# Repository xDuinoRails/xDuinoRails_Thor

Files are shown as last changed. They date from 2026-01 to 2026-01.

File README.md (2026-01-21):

# mtc21/plux16 Semi-Decoder for Seeed XIAO boards

Make a Seeed XIAO board a mtc21 decoder, all the electronics needed is on this little board:
- mtc21/plux16 compatible connector
- DC Motor
- 2x Functions
- DCC / DCC-ACK / RailCom

Open-Source [schematics](xDuinoRails-Thor-M-schematic.pdf) and [PCB design](xDuinoRails-Thor-M-PCB_All.pdf) included.

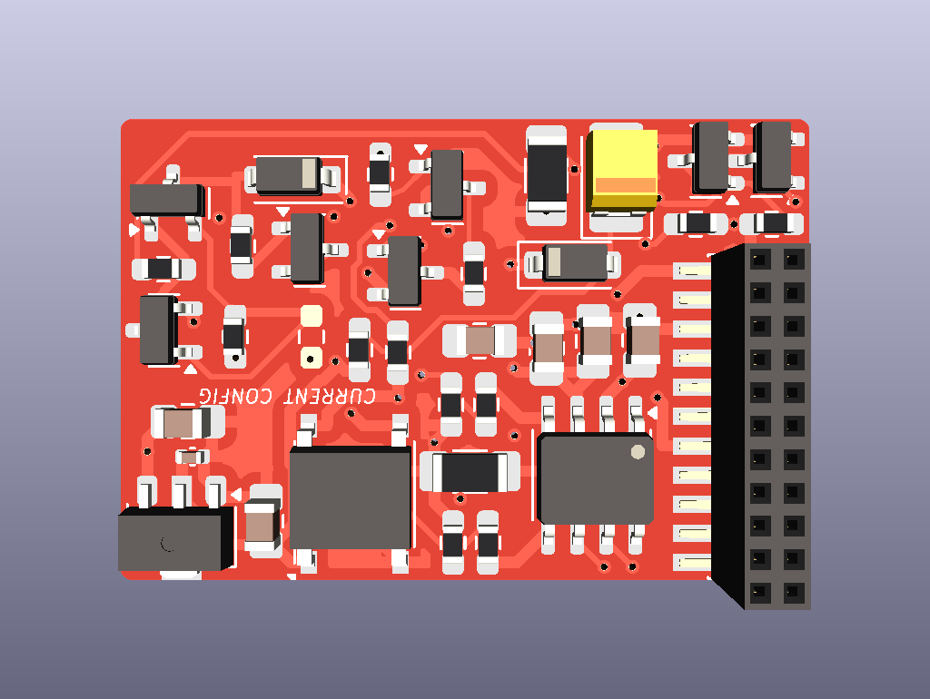
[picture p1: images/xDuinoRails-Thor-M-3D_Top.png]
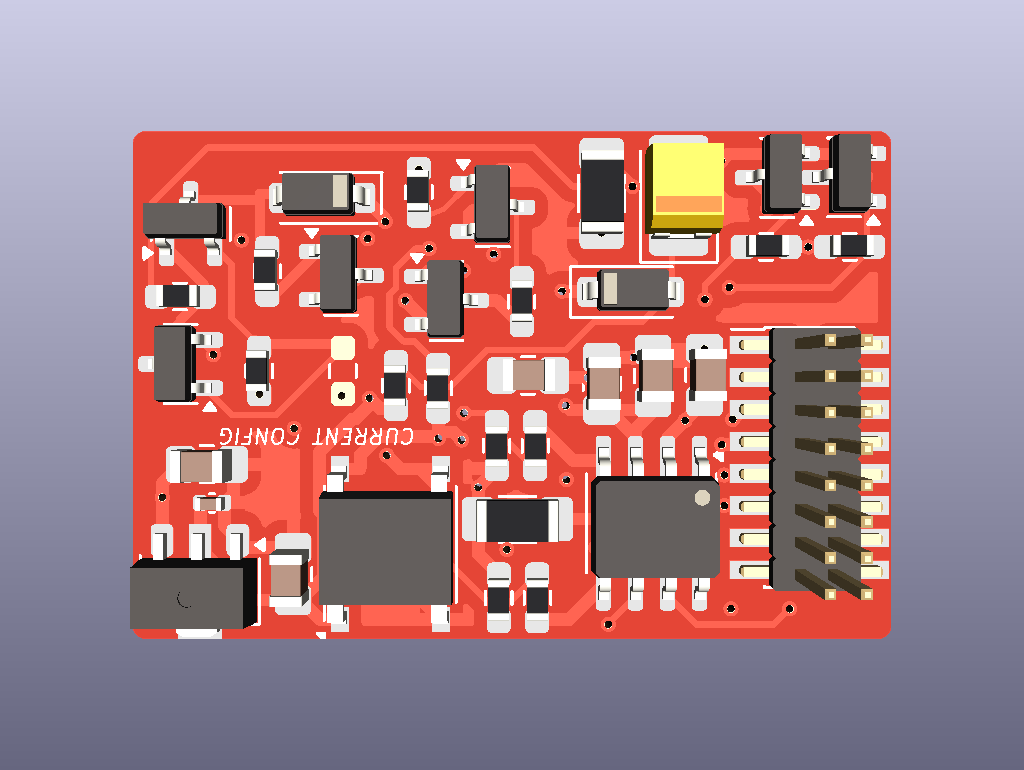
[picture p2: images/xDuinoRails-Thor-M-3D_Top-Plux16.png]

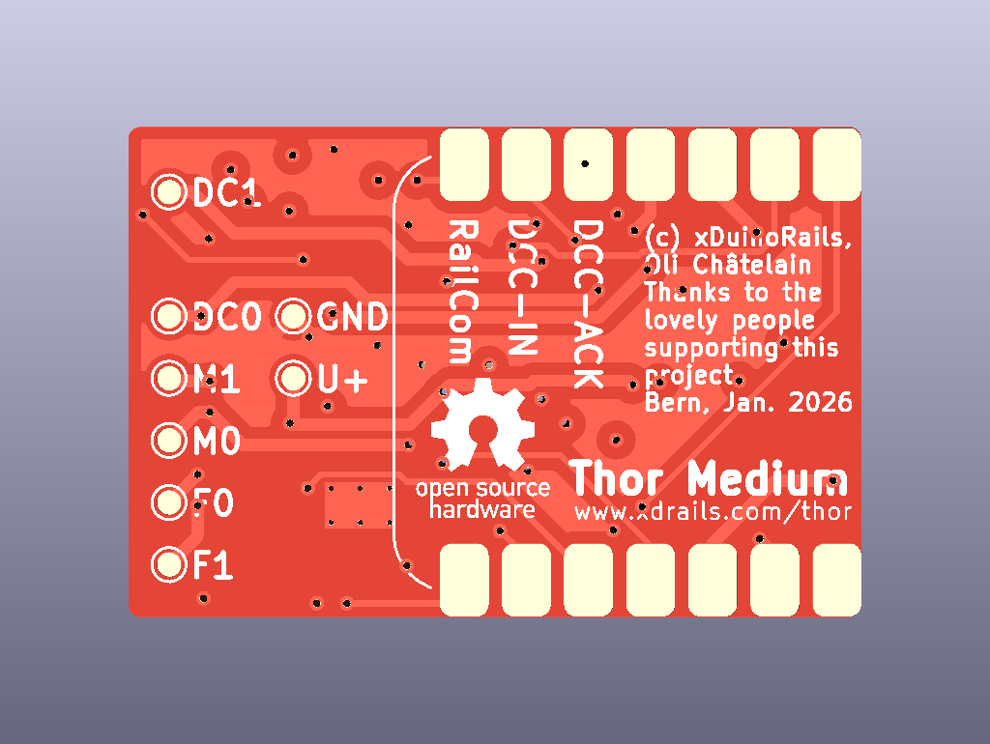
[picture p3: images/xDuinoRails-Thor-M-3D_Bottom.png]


## Wiring

```
                     +--------------------+      +--------------------+         +---------------+
                     |      RP2040        |      |     BDR-6133       |         |     Motor     |
                     |    (Top View)      |      |    Motor Driver    |         | DC brushed    |
                     +--------------------+      +--------------------+         +---------------+
                     |                5v  |      |                    |         |               |
          ---``|<----| D15 (LED)      GND |      |                    |         |               |
          ---``|<----| D16 (LED)      3v3 |      |                    |         |               |
                     |                    |      |                    |         |               |
                     |        (PWM B) D8  |----->| InB           OutB |=====+==>| B             |
                     |        (PWM A) D7  |----->| InA           OutA |==+==|==>| A             |
                     |                    |      +---------+----------+  |  |   +---------------+
                     |       (Shut)   A2  |<.............../             |  |
                     |       (bEMF B) A1  |<----------------------------/   |
                     |       (bEMF A) A0  |<-------------------------------/
                     |                    |
                     |                    |      +--------------------+
                     |                    |      | Functions          |
                     |                    |      +--------------------+
                     |         F0f    D9  |----->| F0f                |
                     |         F0b    D10 |----->| F0b                |
                     |                    |      +---------+----------+
                     |       (Shut)   A3  |<.............../

                     |                    |      +--------------------+
                     |                    |      | DCC / Railcom      |
                     |                    |      +--------------------+
                     |     DCC-ACK    D4  |----->| DCC-ACK            |
                     |     DCC/MM/SX  D5  |<-----| DCC/MM/SX          |
                     |     RailCom    D6  |----->| RailCom            |
                     |                    |      +---------+----------+
                     |       (Shut)   A3  |<.............../
                     +--------------------+
```

## Purchase your copy

If you want an easy way to try this board, order one on tindie:
- https://www.tindie.com/products/chatelao/diy-dccmm-decoder-for-xiao-boards

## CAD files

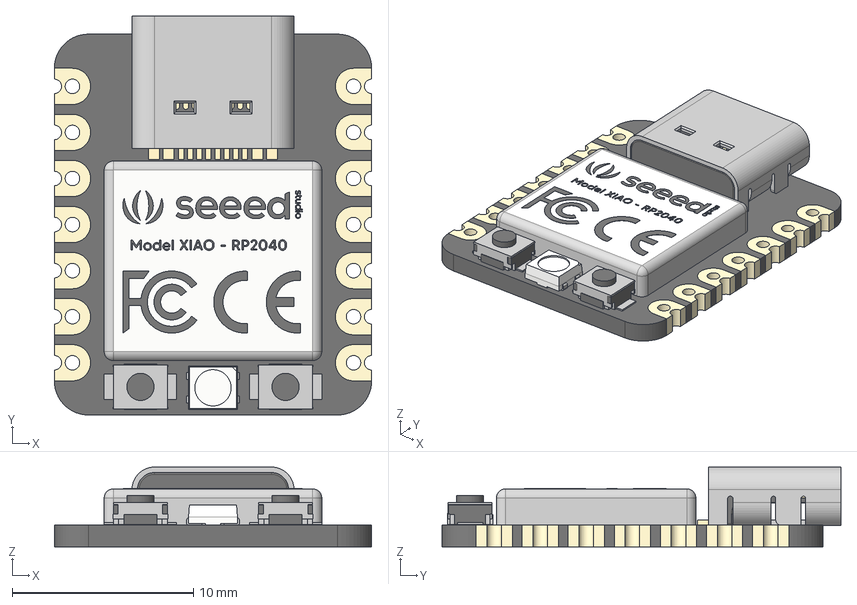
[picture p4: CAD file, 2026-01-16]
__lib/3d/SeeedStudio-XIAO_RP2040-v26.step
17.5 x 22.0 x 4.40 mm
type-c v2
smd_button v3
DOUT
DIN
VSS
VDD
smd_button v3(Mirror)

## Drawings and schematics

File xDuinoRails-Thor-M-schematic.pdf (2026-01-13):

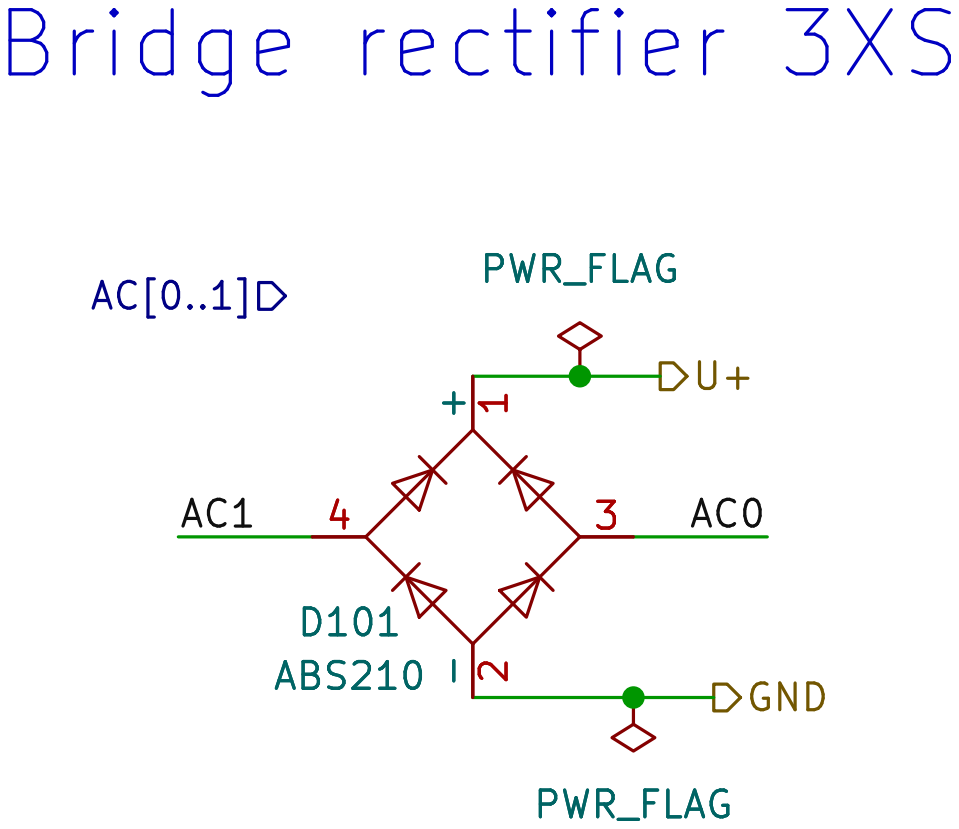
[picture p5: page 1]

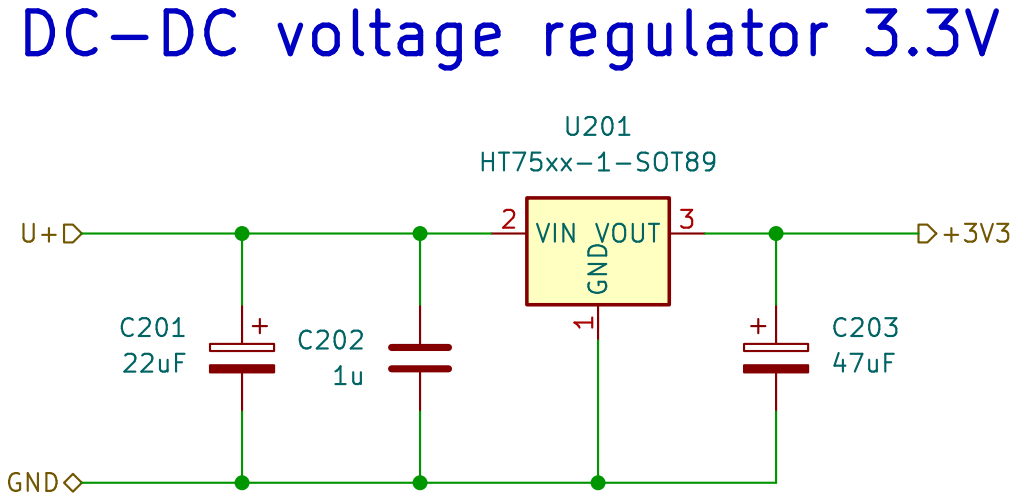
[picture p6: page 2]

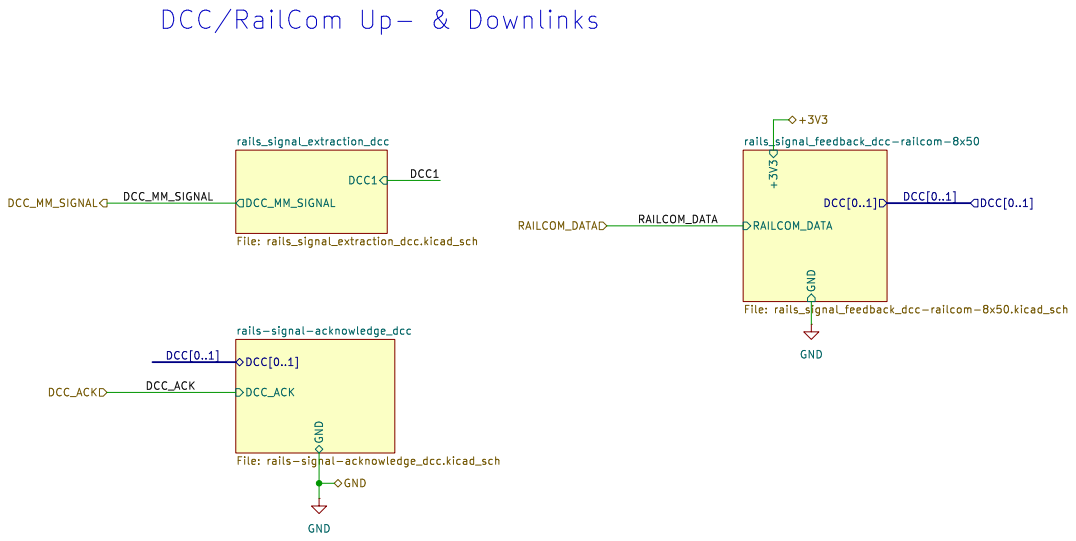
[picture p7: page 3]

rails-signal-acknowledge_dcc File: rails-signal-acknowledge_dcc.kicad_sch

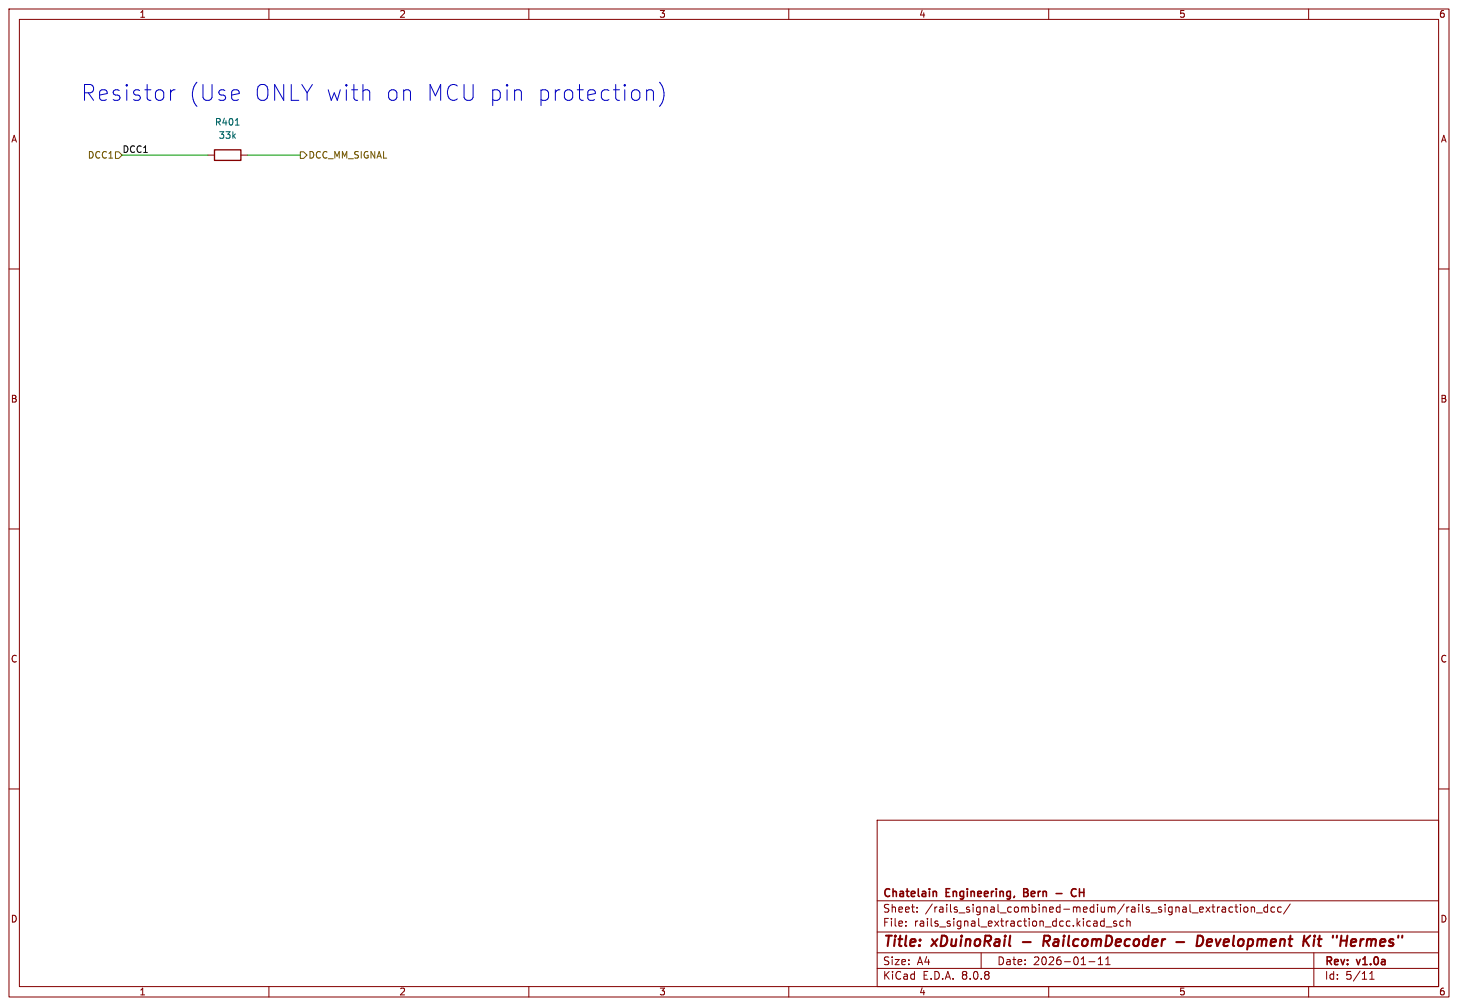
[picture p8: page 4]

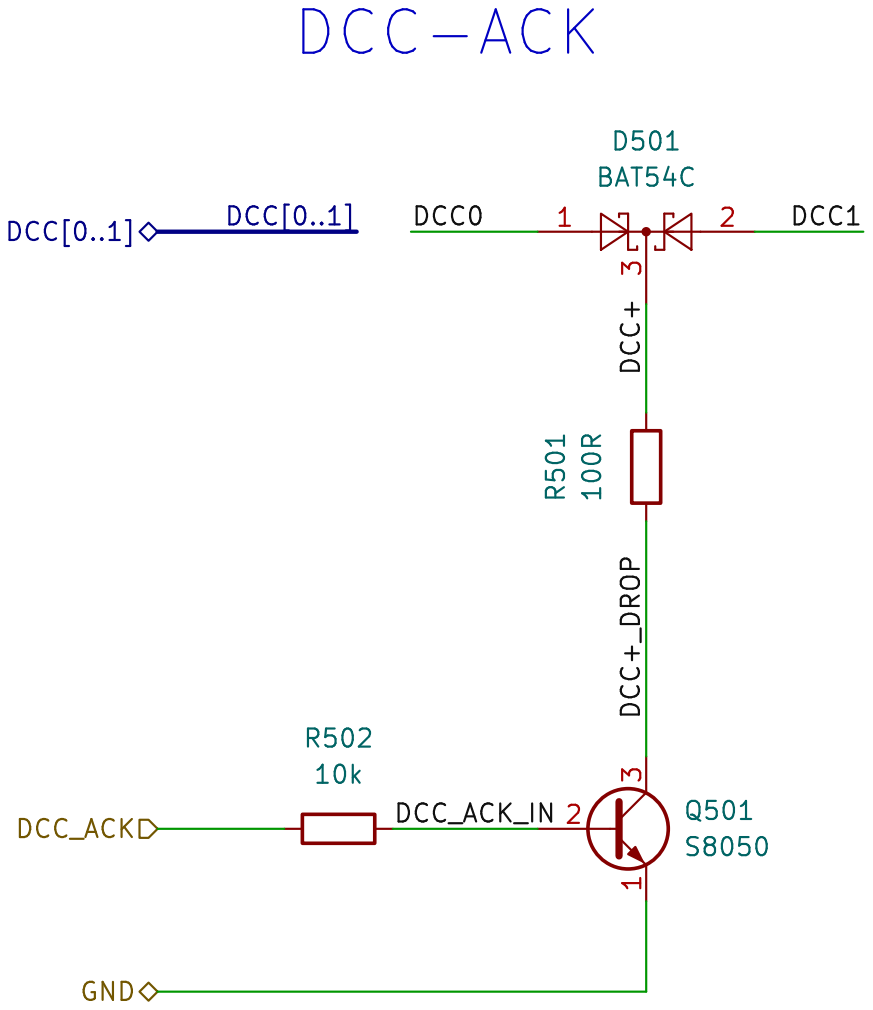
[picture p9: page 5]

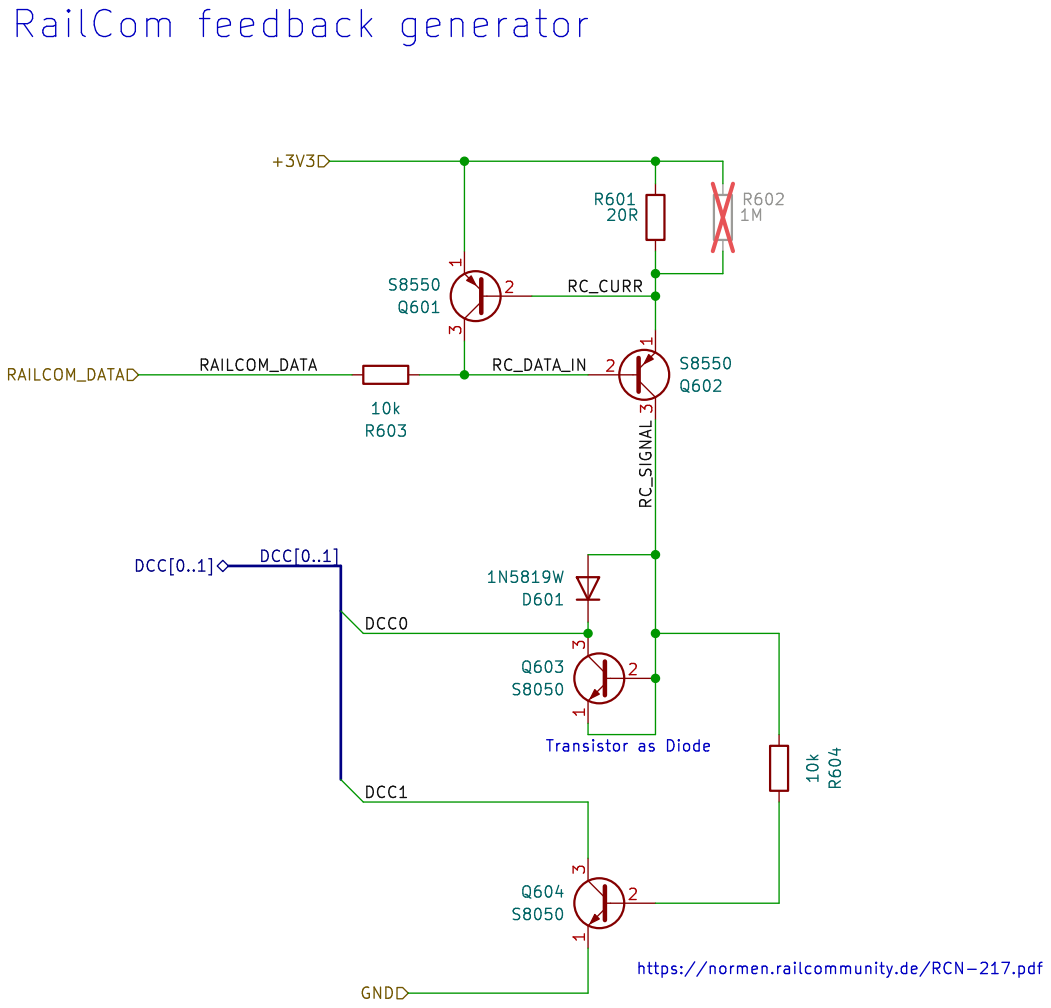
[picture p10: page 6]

https://normen.railcommunity.de/RCN-217.pdf

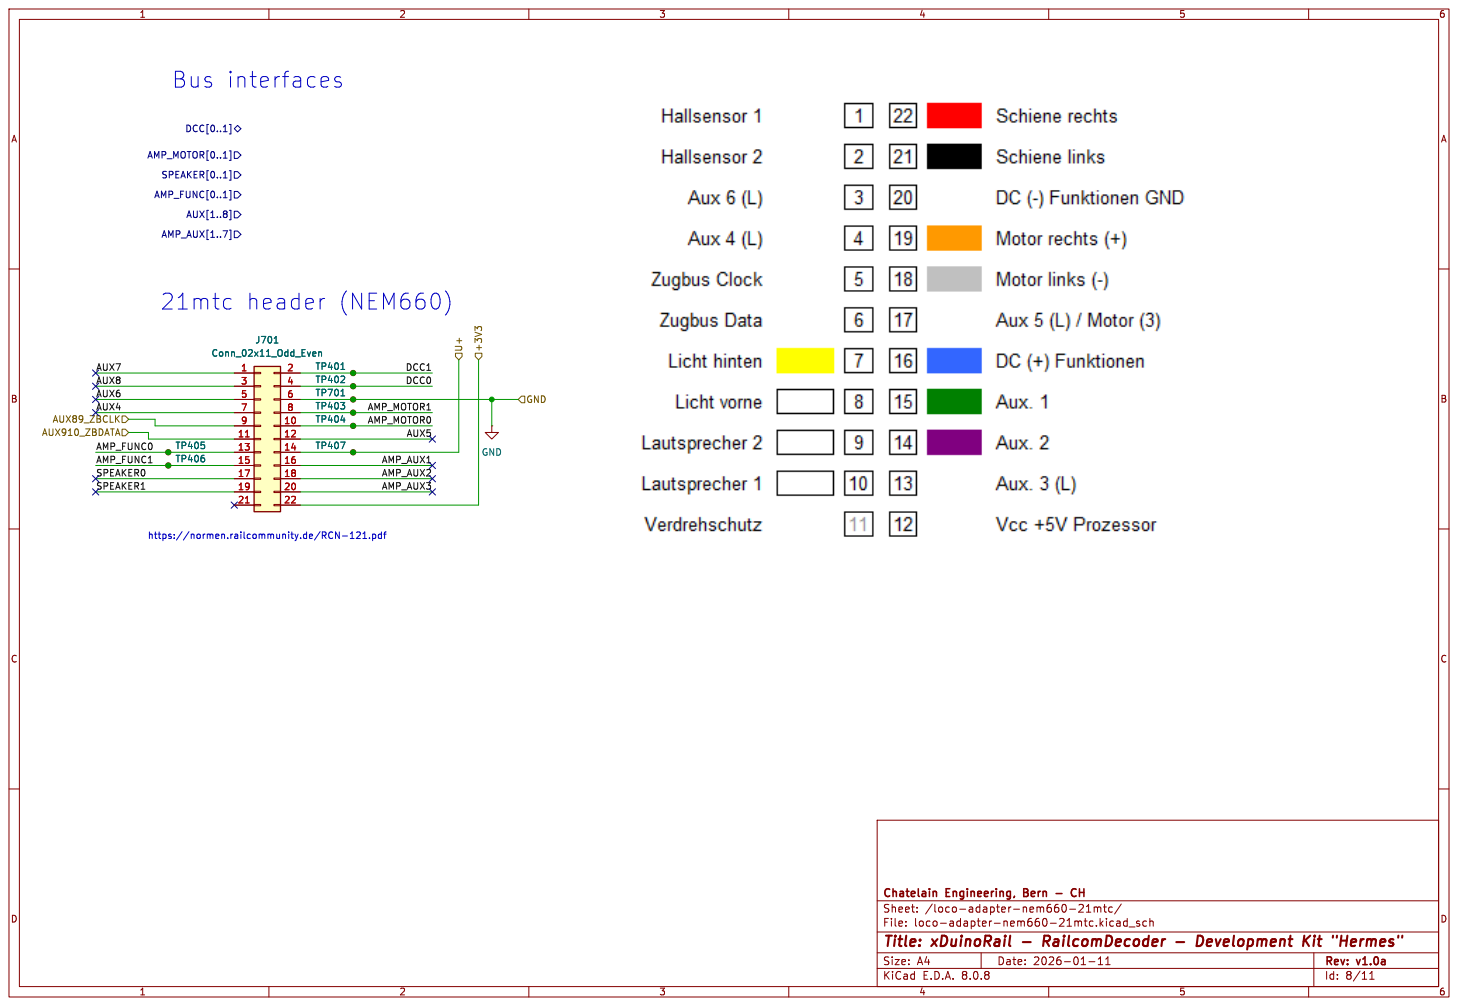
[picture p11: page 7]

https://normen.railcommunity.de/RCN-121.pdf

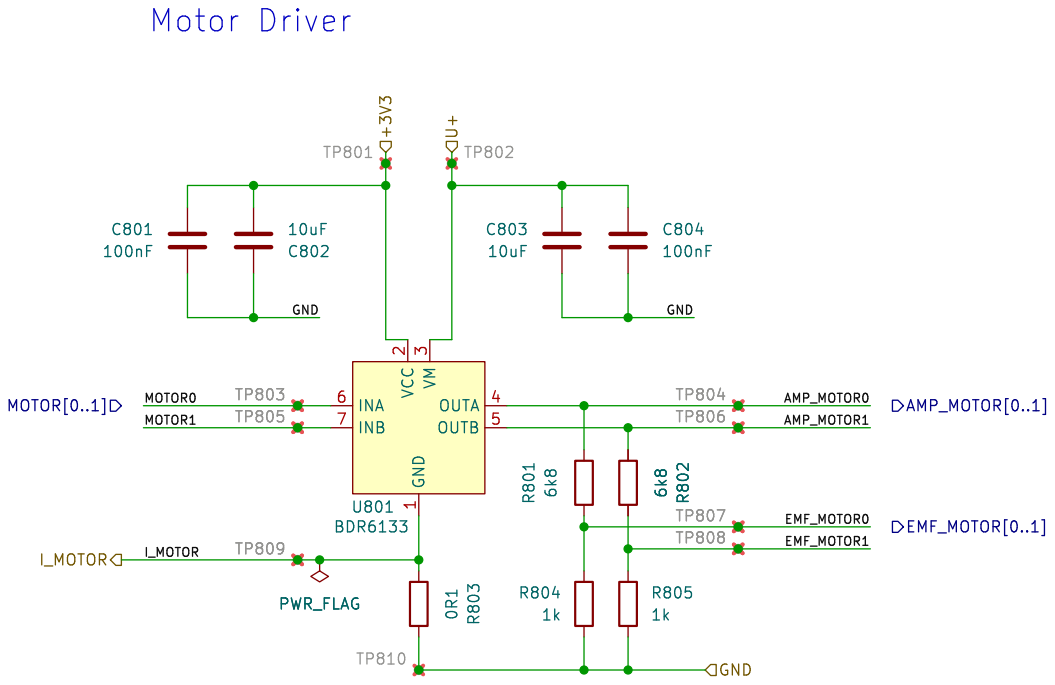
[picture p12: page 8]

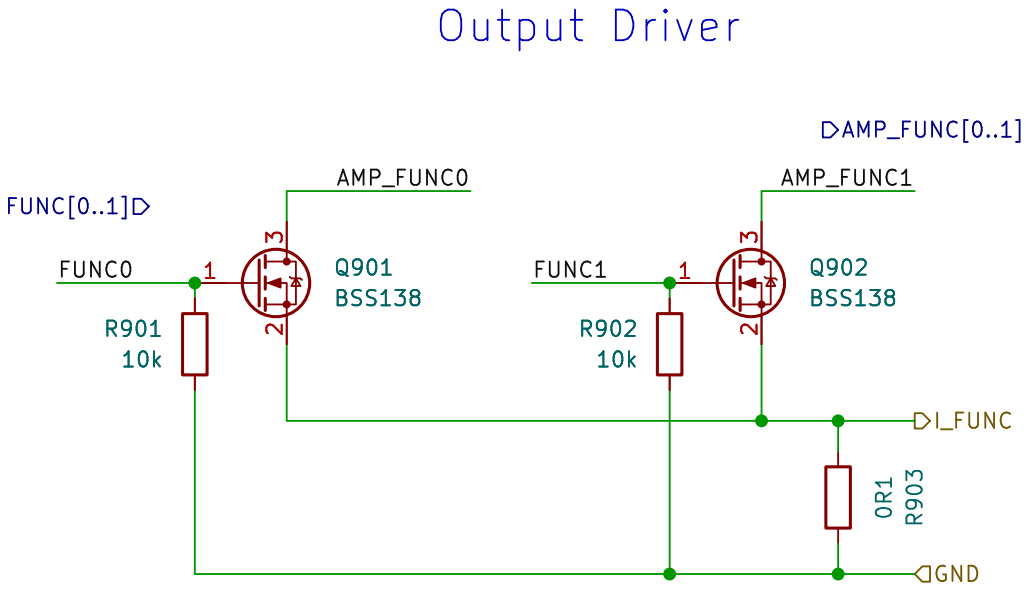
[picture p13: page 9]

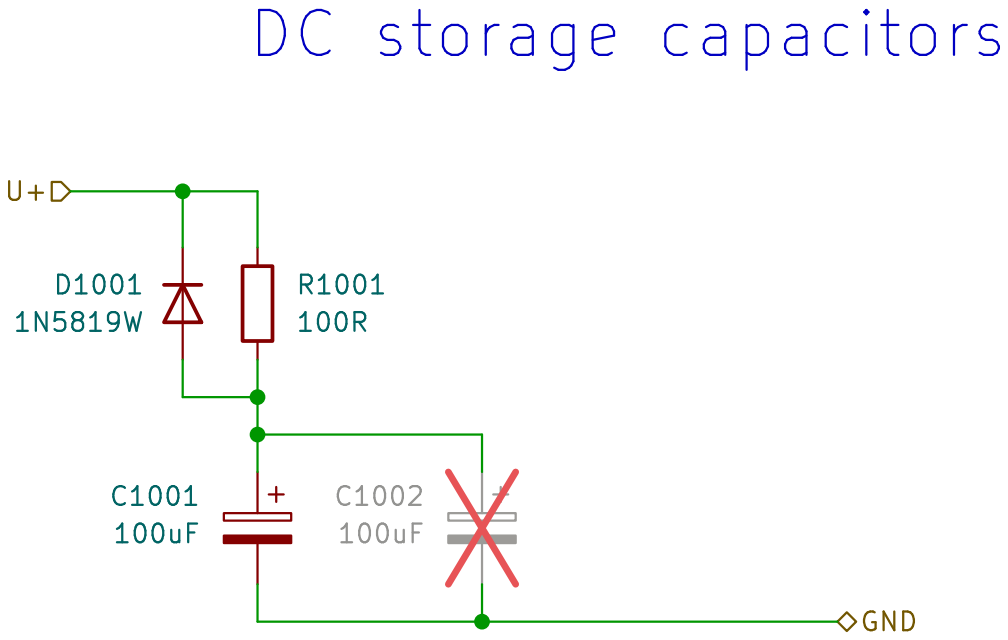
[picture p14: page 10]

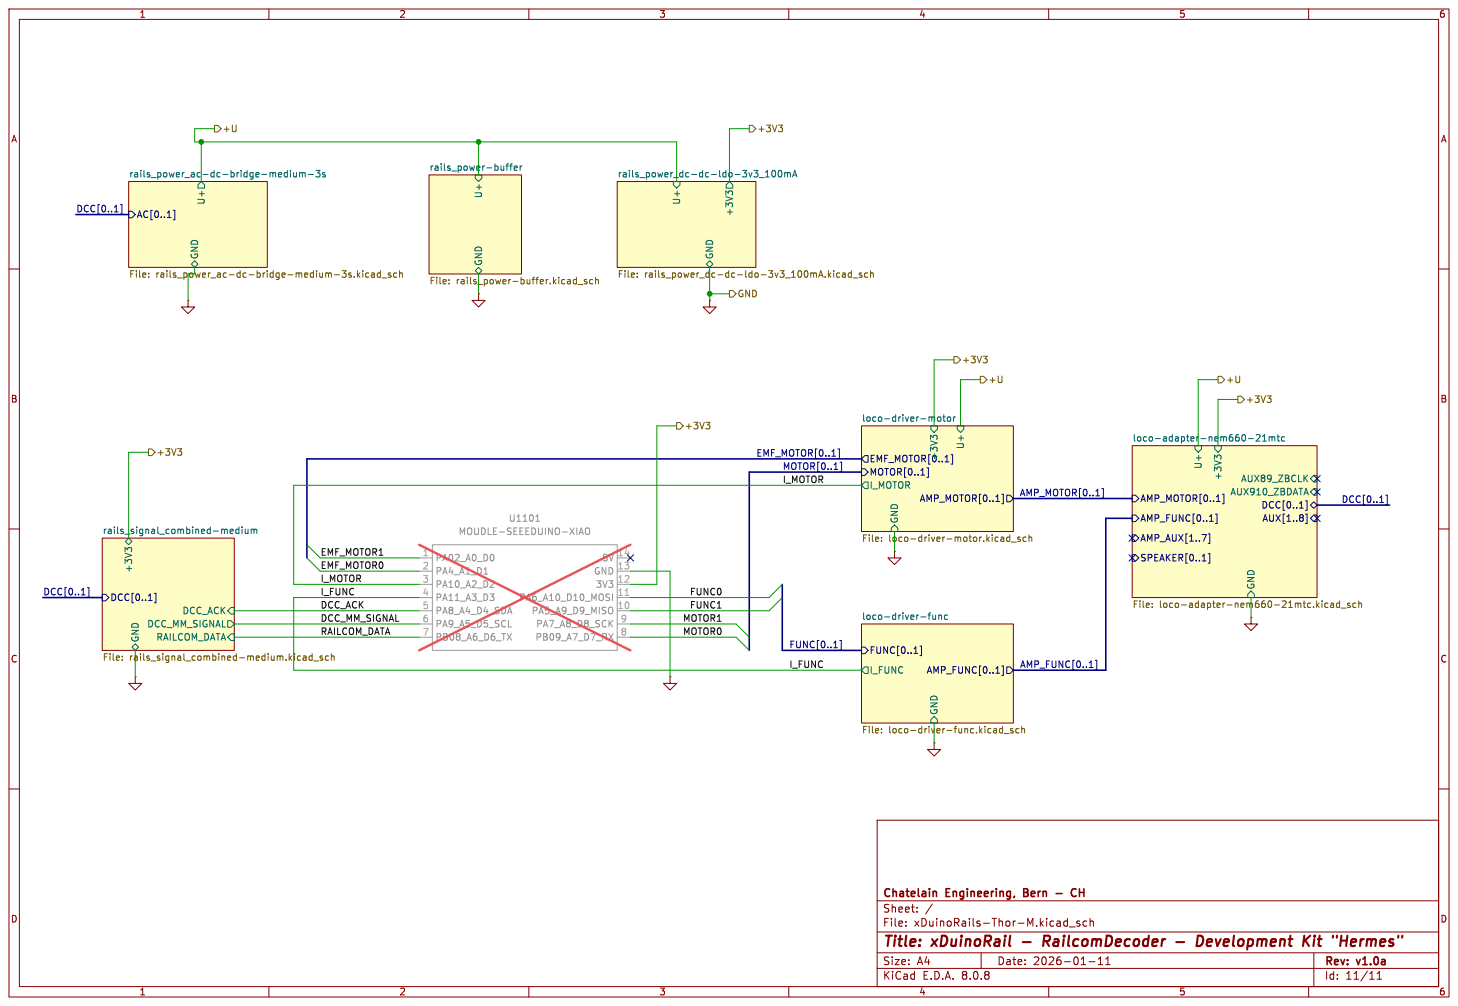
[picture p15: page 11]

loco-driver-func File: loco-driver-func.kicad_sch EMF_MOTOR[0..1]
MOTOR[0..1]
I_MOTOR

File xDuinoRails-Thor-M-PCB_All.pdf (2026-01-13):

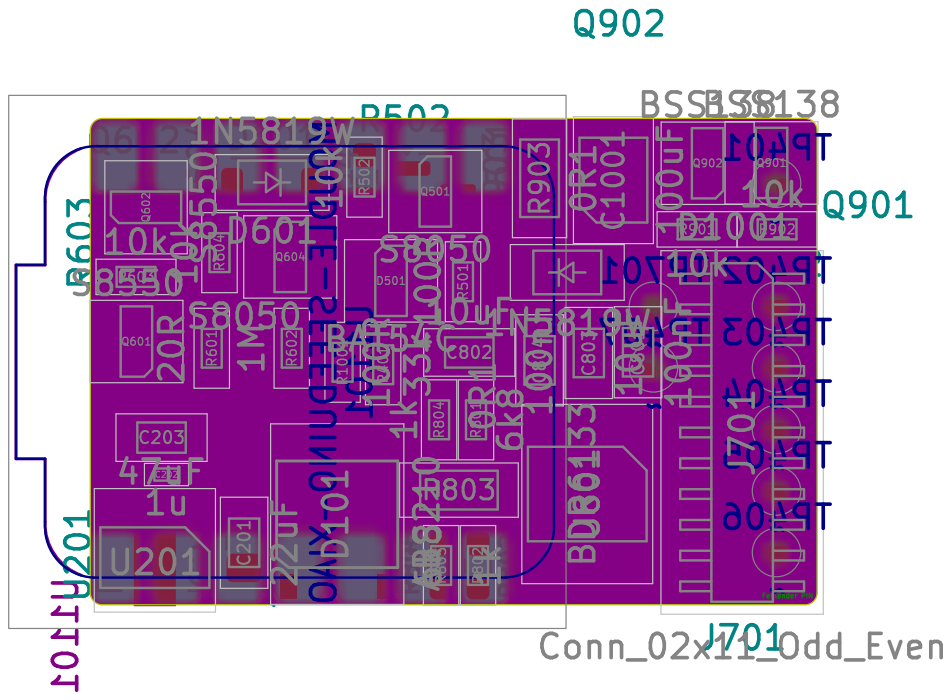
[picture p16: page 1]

project. | 10uF | C804 | 10k R901 GND TP407

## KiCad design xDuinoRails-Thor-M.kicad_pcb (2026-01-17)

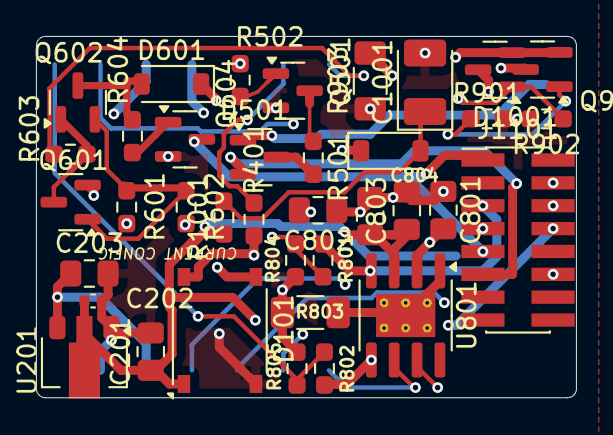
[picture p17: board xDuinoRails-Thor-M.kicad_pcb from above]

Board: 6 copper layers, 30.0 x 20.1 mm, 38 parts (1 on the bottom side), 28 nets.

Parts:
C201: 22uF; C_0805_2012Metric_Pad1.18x1.45mm_HandSolder
C202: 1u; C_0402_1005Metric
C203: 47uF; C_0805_2012Metric_Pad1.18x1.45mm_HandSolder
C801, C804: 100nF; C_0805_2012Metric_Pad1.18x1.45mm_HandSolder
C802, C803: 10uF; C_0805_2012Metric_Pad1.18x1.45mm_HandSolder
C1001: 100uF; CP_EIA-3528-21_Kemet-B_Pad1.50x2.35mm_HandSolder
D101: ABS210; Diode_Bridge_Diotec_ABS
D501: BAT54C; 8x50_SOT-23
D601, D1001: 1N5819W; D_SOD-123
J1101: Conn_02x08_Odd_Even; PinHeader_2x08_P1.27mm_Vertical_SMD
Q501, Q604: S8050; 8x50_SOT-23
Q601, Q602: S8550; 8x50_SOT-23
Q901, Q902: BSS138; SOT-23
R401: 33k; R_0603_1608Metric_Pad0.98x0.95mm_HandSolder
R501, R1001: 100R; R_0603_1608Metric_Pad0.98x0.95mm_HandSolder
R502, R603, R604, R901, R902: 10k; R_0603_1608Metric_Pad0.98x0.95mm_HandSolder
R601: 20R; R_0603_1608Metric_Pad0.98x0.95mm_HandSolder
R602: 1M; R_0603_1608Metric_Pad0.98x0.95mm_HandSolder
R801, R802: 6k8; R_0603_1608Metric_Pad0.98x0.95mm_HandSolder
R803, R903: 0R1; R_1206_3216Metric_Pad1.30x1.75mm_HandSolder
R804, R805: 1k; R_0603_1608Metric_Pad0.98x0.95mm_HandSolder
U201: HT75xx-1-SOT89; SOT-89-3
U801: BDR6133; SOIC-8-1EP_3.9x4.9mm_P1.27mm_EP2.41x3.3mm_ThermalVias
U1301: MOUDLE-SEEEDUINO-XIAO; XIAO_SMD

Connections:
/+3V3: C203.1, C801.1, C802.2, Q601.1 (E), R601.2, R602.2, U201.3 (VOUT), U801.2 (VCC), U1301.12 (3V3)
/+U: C201.1, C202.1, C803.1, C804.1, D101.1 (+), D1001.1 (K), J1101.8, R1001.1, U201.2 (VIN), U801.3 (VM)
/AMP_FUNC0: J1101.6, Q901.3 (D)
/AMP_FUNC1: J1101.12, Q902.3 (D)
/AMP_MOTOR0: J1101.5, R801.2, U801.4 (OUTA)
/AMP_MOTOR1: J1101.7, R802.2, U801.5 (OUTB)
/DCC0: D101.3, D501.1, D601.1 (K), J1101.11
/DCC1: D101.4, D501.2, J1101.9, Q604.3 (C), R401.1
/DCC_ACK: R502.1, U1301.5 (PA8_A4_D4_SDA)
/DCC_MM_SIGNAL: R401.2, U1301.6 (PA9_A5_D5_SCL)
/EMF_MOTOR0: R801.1, R804.1, U1301.2 (PA4_A1_D1)
/EMF_MOTOR1: R802.1, R805.1, U1301.1 (PA02_A0_D0)
/FUNC0: Q901.1 (G), R901.1, U1301.11 (PA6_A10_D10_MOSI)
/FUNC1: Q902.1 (G), R902.1, U1301.10 (PA5_A9_D9_MISO)
/I_FUNC: Q901.2 (S), Q902.2 (S), R903.2, U1301.4 (PA11_A3_D3)
/MOTOR0: U801.6 (INA), U1301.8 (PB09_A7_D7_RX)
/MOTOR1: U801.7 (INB), U1301.9 (PA7_A8_D8_SCK)
/RAILCOM_DATA: R603.2, U1301.7 (PB08_A6_D6_TX)
/rails_signal_combined-medium/rails-signal-acknowledge_dcc/DCC+: D501.3, R501.2
/rails_signal_combined-medium/rails-signal-acknowledge_dcc/DCC+_DROP: Q501.3 (C), R501.1
/rails_signal_combined-medium/rails-signal-acknowledge_dcc/DCC_ACK_IN: Q501.2 (B), R502.2
/rails_signal_combined-medium/rails_signal_feedback_dcc-railcom-8x50/RC_CURR: Q601.2 (B), Q602.1 (E), R601.1, R602.1
/rails_signal_combined-medium/rails_signal_feedback_dcc-railcom-8x50/RC_DATA_IN: Q601.3 (C), Q602.2 (B), R603.1
/rails_signal_combined-medium/rails_signal_feedback_dcc-railcom-8x50/RC_SIGNAL: D601.2 (A), Q602.3 (C), R604.1
GND: C201.2, C202.2, C203.2, C801.2, C802.1, C803.2, C804.2, C1001.2, D101.2 (-), J1101.4, Q501.1 (E), Q604.1 (E), R803.1, R804.2, R805.2, R901.2, R902.2, R903.1, U201.1 (GND), U1301.13 (GND)
unnamed: C1001.1, D1001.2 (A), R1001.2
unnamed: Q604.2 (B), R604.2
PGND: R803.2, U801.1 (GND), U801.9 (PGND), U1301.3 (PA10_A2_D2)

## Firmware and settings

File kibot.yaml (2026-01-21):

kibot:
  version: 1

filters:
  - name: 'hide_refs'
    comment: 'Ersetzt den Referenz-Text durch ein Leerzeichen'
    type: field_modify
    fields: ['Reference']
    regex: '.*'
    replace: ' '

variants:
  - name: 'clean_render_variant'
    comment: 'Variante ohne sichtbare Referenzen'
    type: kibom
    pre_transform:
      - 'hide_refs'

  - name: 'production_variant'
    comment: 'Ungefilterte Daten für die Fertigung'
    type: kibom

preflight:
  erc:
    enabled: true
    warnings_as_errors: false
  drc:
    enabled: false
    warnings_as_errors: false

outputs:
  - name: 'PDF_Schaltplan'
    comment: 'Erzeugt ein PDF des Schaltplans'
    type: pdf_sch_print
    dir: '.'

  - name: 'PDF_PCB_alle_Lagen_zusammen'
    comment: "Alle PCB Lagen in einem PDF"
    type: pcb_print
    options:
      format: PDF
      output: '%f-PCB_All.pdf'
      pages:
        - layers: all
          sheet: 'S.'

  - name: 'PDF_PCB_alle_Lagen_einzeln_gross'
    comment: "Alle PCB Lagen Gross (Migriert)"
    type: pcb_print
    options:
      format: PDF
      output: '%f-PCB_All_Layers_Big.pdf'
      scaling: 0
      plot_sheet_reference: true
      pages:
        - layers: [ 'F.Cu' ]
        - layers: [ 'In1.Cu' ]
        - layers: [ 'In2.Cu' ]
        - layers: [ 'B.Cu' ]
        - layers: [ 'F.SilkS' ]
        - layers: [ 'B.SilkS' ]
        - layers: [ 'F.Mask' ]
        - layers: [ 'B.Mask' ]
        - layers: [ 'Edge.Cuts' ]
        - layers: [ 'F.Fab' ]

  - name: '3D_Top_View'
    comment: "Render der Oberseite (KiCad Internal)"
    type: render_3d
    dir: 'images'
    options:
      pre_transform: hide_refs
      width: 2048
      height: 1536
      view: top      
      variant: 'clean_render_variant'
      output: '%f-3D_Top.png'

  - name: '3D_Bottom_View'
    comment: "Render der Unterseite (KiCad Internal)"
    type: render_3d
    dir: 'images'
    options:
      pre_transform: hide_refs
      width: 2048
      height: 1536
      view: bottom
      # ray_tracing: true
      output: '%f-3D_Bottom.png'

  - name: 'Interactive_BOM'
    comment: 'Erzeugt eine interaktive HTML-Stückliste (iBOM)'
    type: ibom
    options:
      dark_mode: true
      sort_order: 'C,R,L,D,U,J,T'
      show_fields: 'Value,Footprint'
      group_fields: 'Value,Footprint'
      output: '%f-iBOM.html'

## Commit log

2026-01-12 Add kibot.yaml configuration for PCB generation
2026-01-12 Add KiCad DRC and ERC checks workflow
    This workflow performs DRC and ERC checks for KiCad projects, uploads artifacts, and creates a release if a version tag is pushed.
2026-01-12 Add - initial version
    [loco-adapter-nem660-21mtc.kicad_sch, loco-driver-func.kicad_sch, loco-driver-motor.kicad_sch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]
2026-01-12 Fix - Remove ERC error, refresh annotation
    [loco-adapter-nem660-21mtc.kicad_sch, loco-driver-func.kicad_sch, loco-driver-motor.kicad_sch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]
2026-01-12 Fix - revert to working model
    [loco-adapter-nem660-21mtc.kicad_sch, loco-driver-func.kicad_sch, loco-driver-motor.kicad_sch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]
2026-01-12 Fix - Yellow background on subcircuits
    [rails_signal_combined-medium.kicad_sch, xDuinoRails-Thor-M.kicad_pcb, xDuinoRails-Thor-M.kicad_sch]
2026-01-12 Add - Fix ERC errors
    [loco-adapter-nem660-21mtc.kicad_sch, loco-driver-motor.kicad_sch, rails_signal_combined-medium.kicad_sch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]
2026-01-12 Fix - Ignore problems in subsheet
    [rails_signal_feedback_dcc-railcom-8x50.kicad_sch]
2026-01-12 Update kibot.yaml to add Gerber options
    Added options to suppress footprint references and values in Gerber files.
2026-01-12 Add interactive BOM generation configuration
2026-01-12 Fix - Position of labels
    [rails_power_dc-dc-ldo-3v3_100mA.kicad_sch, xDuinoRails-Thor-M.kicad_pcb]
2026-01-12 Fix - Move labels to the right place
    [xDuinoRails-Thor-M.kicad_pcb]
2026-01-12 Fix - BOM errors
    [loco-adapter-nem660-21mtc.kicad_sch, loco-driver-motor.kicad_sch, rails_signal_feedback_dcc-railcom-8x50.kicad_sch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]
2026-01-13 Enhance kibot.yaml with filters and 3D render options
    Added filters and new rendering options for 3D views.
2026-01-13 Update artifact paths in kicad-checks.yml
2026-01-13 Include wiring section in README
    Added wiring diagram for RP2040 and motor driver setup.
2026-01-13 Update README with schematics and PCB design links
    Added links to open-source schematics and PCB design.
2026-01-13 Correct capitalization of 'schematics' in README
2026-01-13 Fix - 100nF capacitor size
    [loco-driver-motor.kicad_sch]
2026-01-16 Fix - 3D model and some silkscreen
    [SeeedStudio-XIAO_RP2040-v26.step, loco-driver-motor.kicad_sch, xDuinoRails-Thor-M.kicad_pcb]
2026-01-17 Chg - Draft of Plux16 connector
    [loco-adapter-nem658-plux16.kicad_sch, loco-adapter-nem660-21mtc.kicad_sch, loco-adapters-2func.kicad_sch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]
2026-01-17 Add - Routing of PluX16 connector
    [xDuinoRails-Thor-M.kicad_pcb]
2026-01-17 Add - New annotations of schematics
    [loco-adapter-nem658-plux16.kicad_sch, loco-adapter-nem660-21mtc.kicad_sch, loco-adapters-2func.kicad_sch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]
2026-01-17 Fix - ERC errors
    [loco-adapters-2func.kicad_sch, xDuinoRails-Thor-M.kicad_pcb]
2026-01-17 Add - Plux16 partnumber
    [loco-adapter-nem658-plux16.kicad_sch, xDuinoRails-Thor-M.kicad_pcb]
2026-01-18 Add - plux16 integration v0.9
    [loco-adapter-nem658-plux16.kicad_sch, loco-adapter-nem660-21mtc.kicad_sch, xDuinoRails-Thor-M - Kopie.kicad_pcb]
2026-01-20 Fix - Component size for 100nF
    [loco-driver-motor.kicad_sch, xDuinoRails-Thor-M - Kopie.kicad_pcb]
2026-01-21 Add rotation correction data for various components
    [rotation_correction.csv]
2026-01-21 Remove unused PCB export configurations
    Removed several PCB printing and export configurations from the kibot.yaml file.
2026-01-21 Update connector description in README.md
2026-01-21 Simplify kicad-checks.yml by removing pinion scripts
    Removed pre-launch and post-launch scripts for pinion installation and execution.
